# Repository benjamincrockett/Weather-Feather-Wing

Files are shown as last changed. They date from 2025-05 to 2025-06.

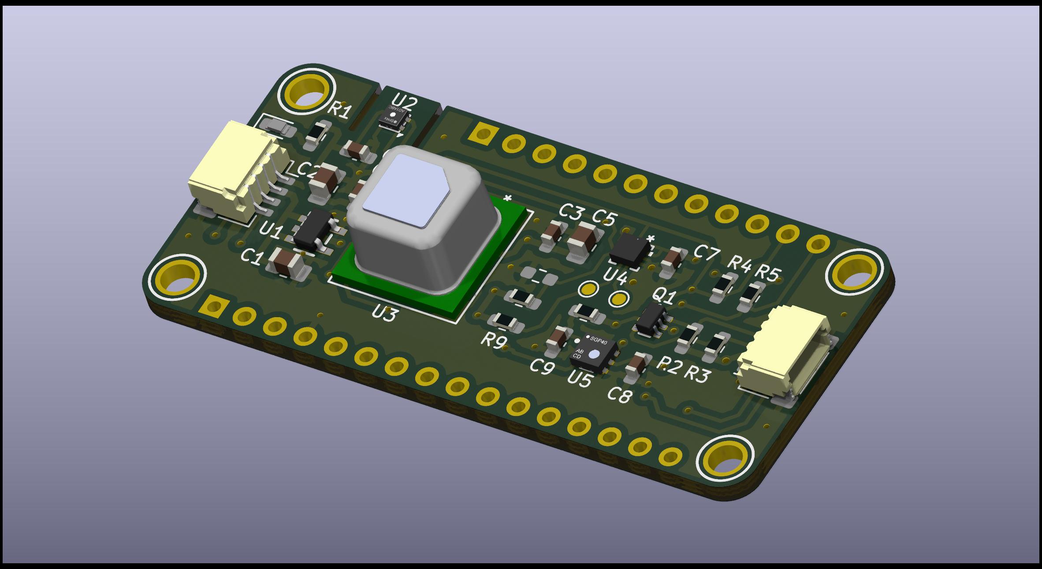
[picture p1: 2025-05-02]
Renders/Weather-Feather-Wing CCA 3D.jpg

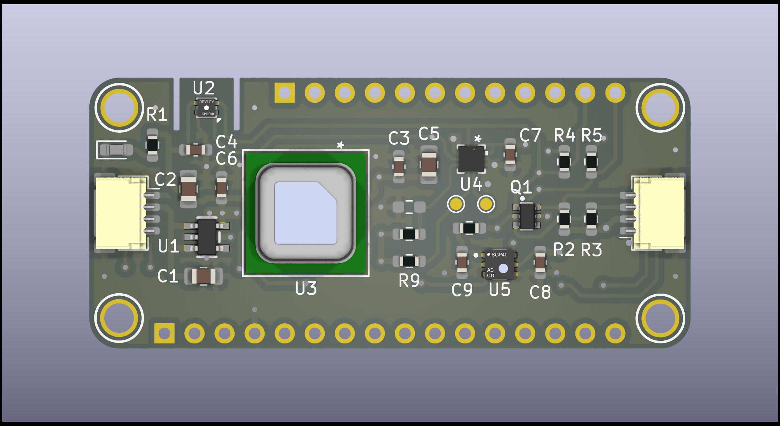
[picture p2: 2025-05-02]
Renders/Weather-Feather-Wing CCA.jpg

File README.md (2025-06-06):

# Weather-Feather-Wing
 An online interactive viewer is available at https://kicanvas.org/. Copy and paste the URL of this repository into the text box on the KiCanvas website to get started. 

# Software
A software example for this project is available in the following repository: https://github.com/benjamincrockett/Air-Quality-Weather

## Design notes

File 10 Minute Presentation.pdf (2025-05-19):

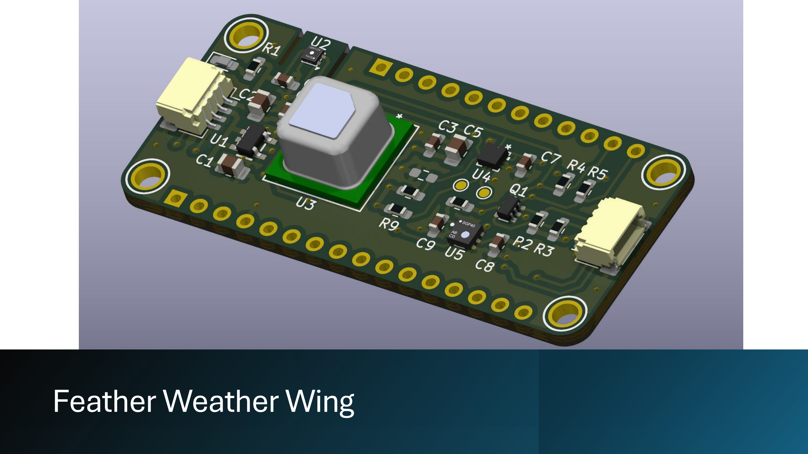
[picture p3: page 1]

# Feather Weather Wing

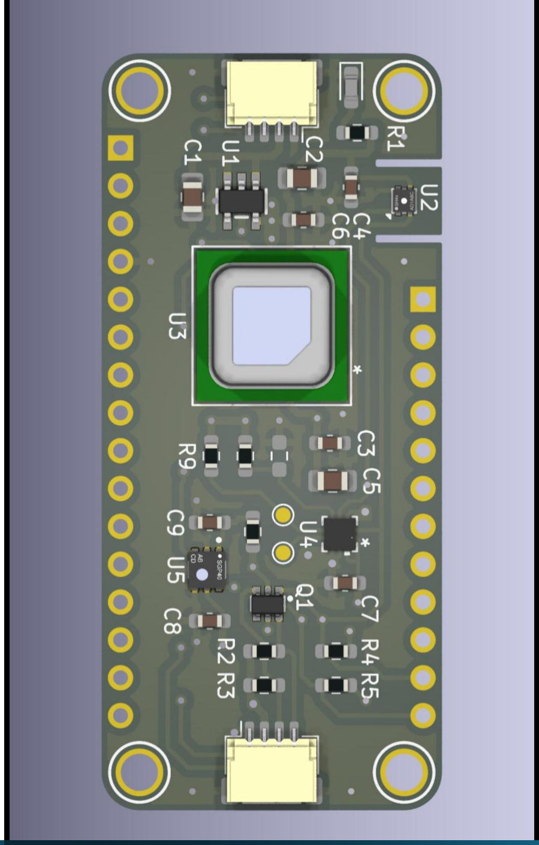
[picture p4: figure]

# Feather Weather Wing: What is it?

# - It is a 0.9-inch x 2.0-inch circuit board that combines four

environmental sensors in the Feather Wing form factor.

# - Sensirion SHT45 – Humidity & Temperature - Sensirion SCD41 – CO2, Temperature, & Humidity

- Benefits from an atmospheric air pressure input.

# - Sensirion SGP40 – Indoor Air Quality

- Benefits from a humidity input.

# - Bosch BMP390 – Atmospheric Air Pressure - 4 Layer PCB - Designed using KiCad 9.0 - PCB fabricated by OSHPARK

# Feather Specification

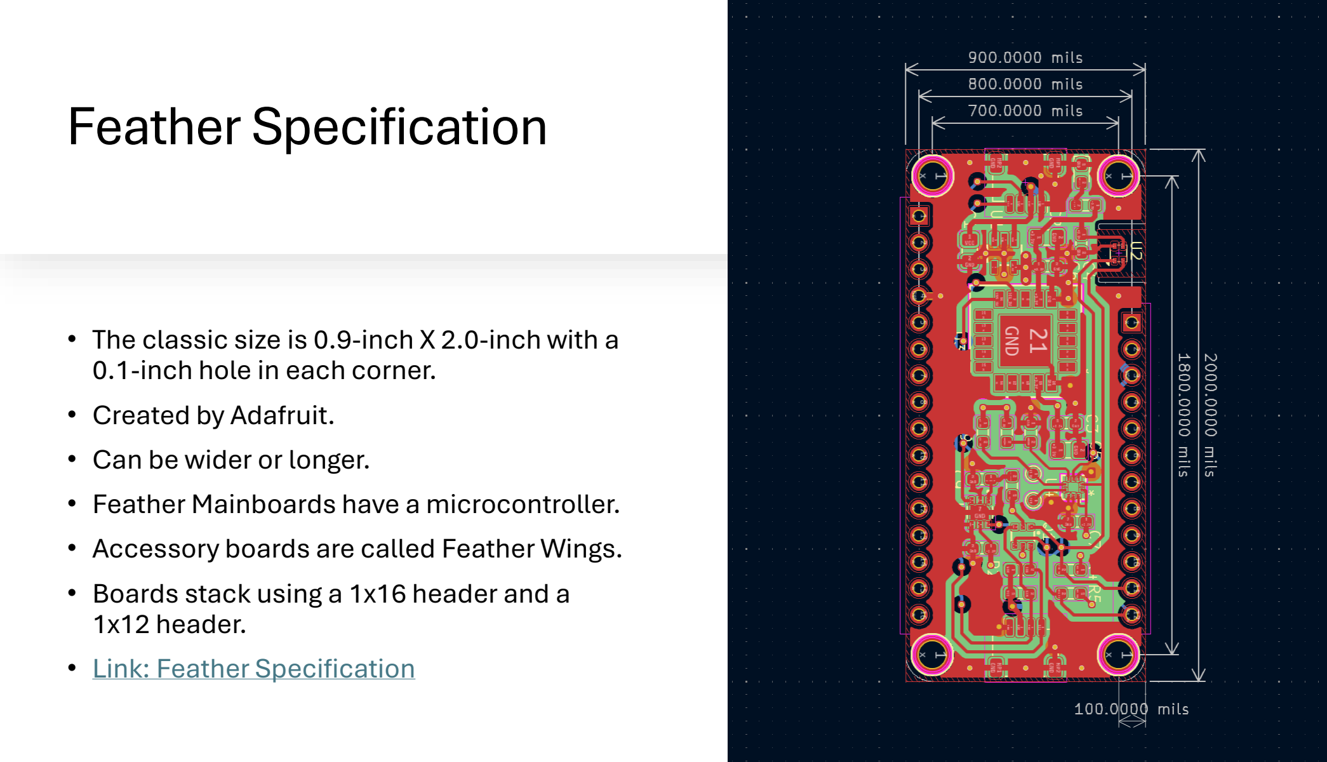
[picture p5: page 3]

# - The classic size is 0.9-inch X 2.0-inch with a

0.1-inch hole in each corner.
- Created by Adafruit.
- Can be wider or longer.
- Feather Mainboards have a microcontroller.
- Accessory boards are called Feather Wings.

# - Boards stack using a 1x16 header and a

1x12 header.
- Link: Feather Specification (https://learn.adafruit.com/adafruit-feather/feather-specification)

# STEMMA QT

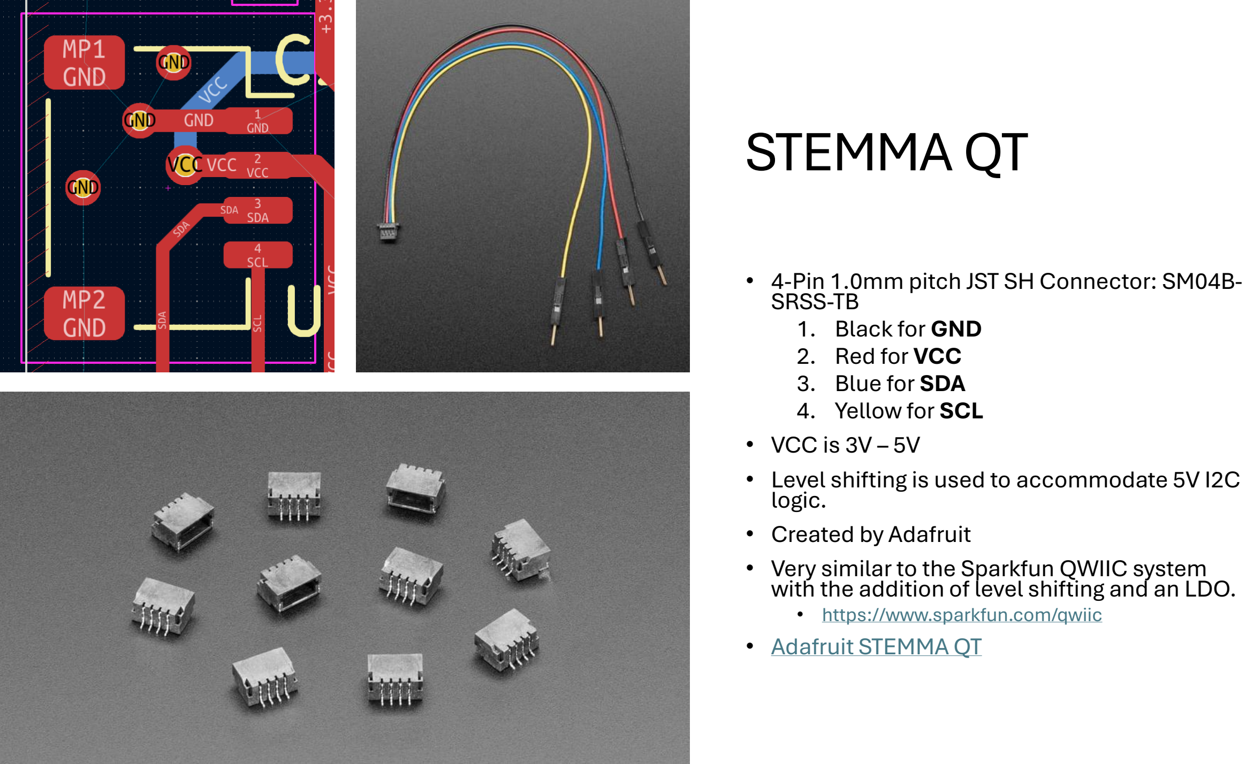
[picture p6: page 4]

# - 4-Pin 1.0mm pitch JST SH Connector: SM04B-SRSS-TB 1. Black for GND 2. Red for VCC 3. Blue for SDA 4. Yellow for SCL - VCC is 3V – 5V - Level shifting is used to accommodate 5V I2C

logic.

# - Created by Adafruit - Very similar to the Sparkfun QWIIC system

with the addition of level shifting and an LDO.

## - https://www.sparkfun.com/qwiic

- Adafruit STEMMA QT (https://learn.adafruit.com/introducing-adafruit-stemma-qt/technical-specs)

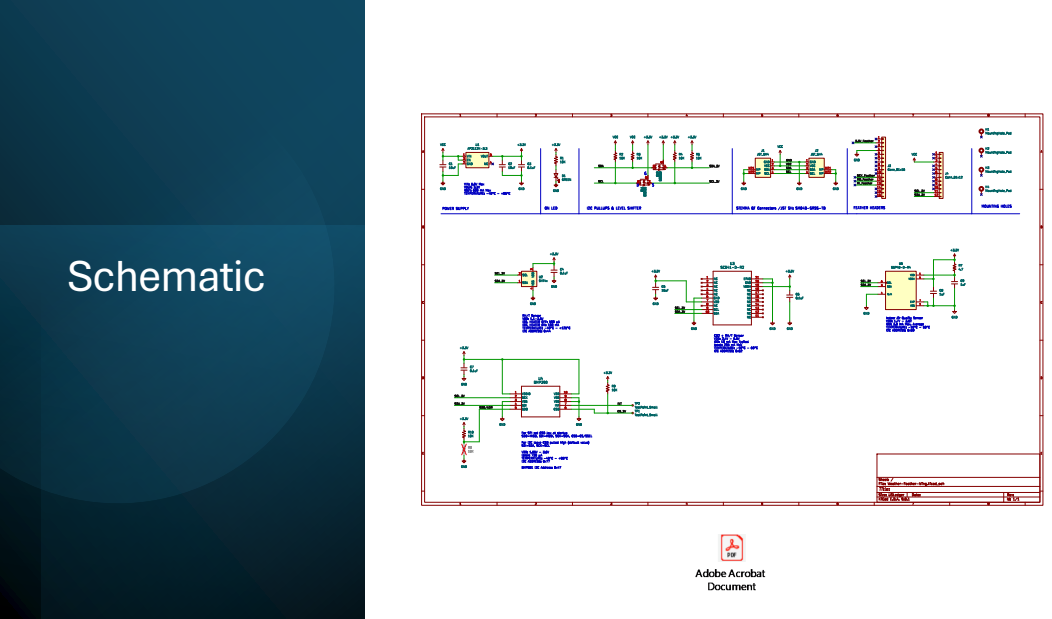
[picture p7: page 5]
Schematic

# Bill Of Materials (BOM)

## Index Reference Description

## Manufacturer Part Number

## Manufacturer

Name | Quantity DNP
1 C1,C2,C5 | CAP CER 10UF 10V X7R 0805 C0805C106K8RACTU | KEMET | 3
2 | C3,C4,C6,C7 | CAP CER 0.1UF 10V X7R 0603 | C0603C104K8RACTU | KEMET | 4
3 C8,C9 | CAP CER 1UF 16V X7R 0603 | C0603C105K4RACTU | KEMET | 2
4 | D1 | LED GREEN DIFFUSED 0603
| | SMD | KT EELP41.12-S2U1-25-2X4X-
| | | 5-R18 | ams-OSRAM USA INC. | 1

5 J1,J2

| | CONN HEADER SMD R/A
| | 4POS 1MM | SM04B-SRSS-TB | JST Sales America Inc. | 2
6 | J3 | Conn_01x16 | - | - | 0 | DNP
7 J4 | Conn_01x12 | - | - | 0 DNP
8 | Q1 | MOSFET 2N-CH 50V 0.2A
| | SOT363 | BSS138DWQ-7 | Diodes Incorporated | 1

9 R1,R2,R3,R4,R5,R9,R10

| | RES SMD 10K OHM 1% 1/10W
| | 0603 | CRCW060310K0FKEA | Vishay Dale | 7
10 | R7 | RES SMD 4.7 OHM 1% 1/10W
| | 0603 | CRCW06034R70FNEA | Vishay Dale | 1

11 R8

| | RES SMD 10K OHM 1% 1/10W
0603 | - | - | 0 DNP
12 | U1 | IC REG LINEAR 3.3V 600MA
| | SOT-25 | AP2112K-3.3TRG1 | Diodes Incorporated | 1
13 U2 | DIGITAL RH/TEMP W/FILTER | SHT45-AD1F-R2 | Sensirion AG | 1
14 | U3 | SENSOR AIR QUALITY I2C
| | OUTPUT | SCD41-D-R2 | Sensirion AG | 1
15 U4 | SENSOR 18.13PSIA 10LGA | BMP390 | Bosch Sensortec | 1
16 | U5 | SENSOR AIR QUALITY I2C
| | OUTPUT | SGP40-D-R4 | Sensirion AG | 1

# Top: Signal /PWR /GND

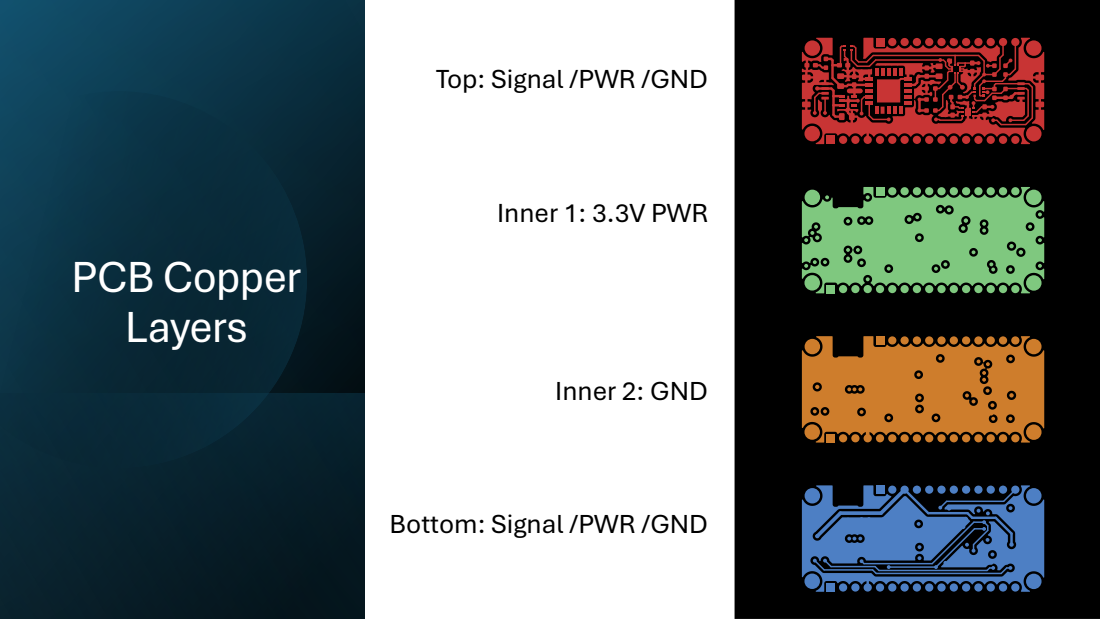
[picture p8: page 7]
PCB Copper Layers; Inner 1: 3.3V PWR; Inner 2: GND

Bottom: Signal /PWR /GND

# Stackup: Four Layer OSHPARK

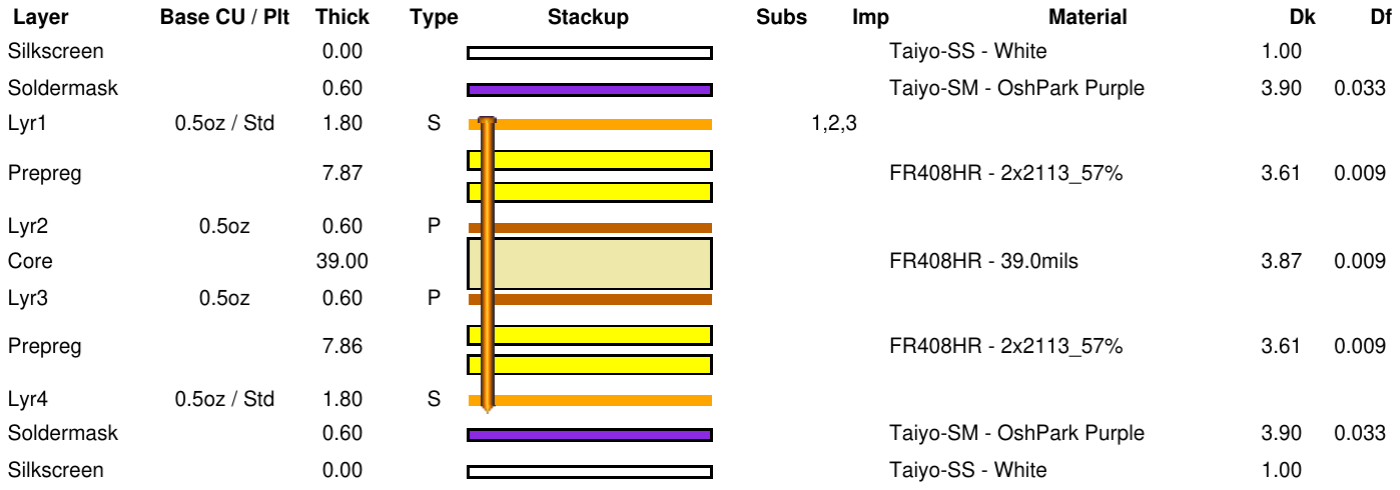
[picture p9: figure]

# Data Logging and Visualization

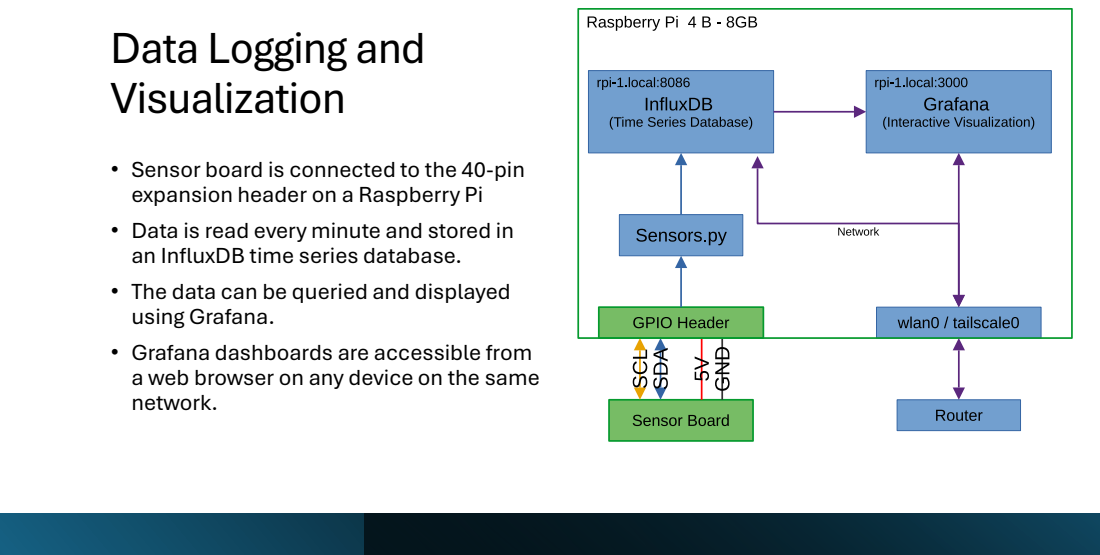
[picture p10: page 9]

• Sensor board is connected to the 40-pin
expansion header on a Raspberry Pi
• Data is read every minute and stored in
an InfluxDB time series database.
• The data can be queried and displayed
using Grafana.
• Grafana dashboards are accessible from
a web browser on any device on the same
network.

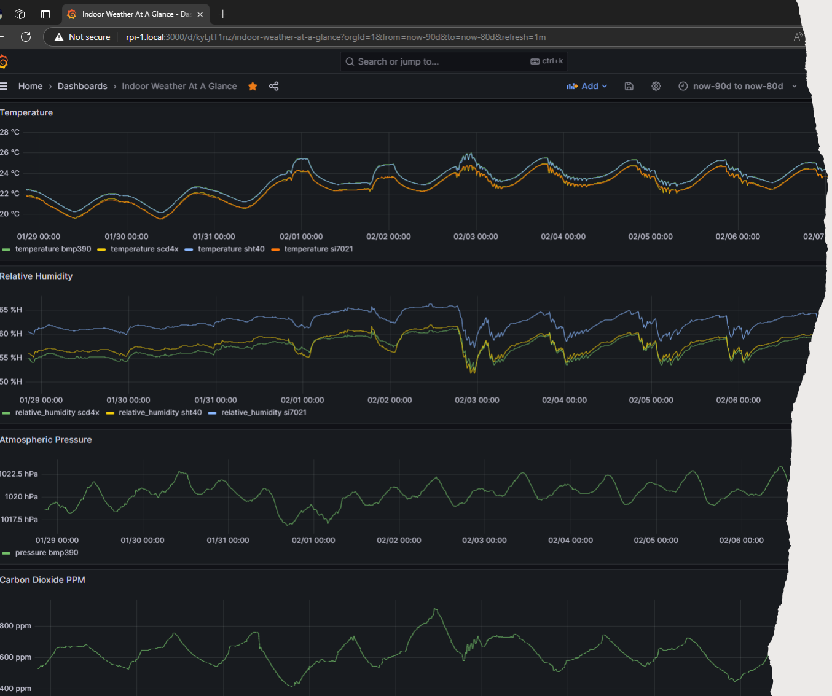
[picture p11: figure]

# Grafana Dashboard

# Data visualization

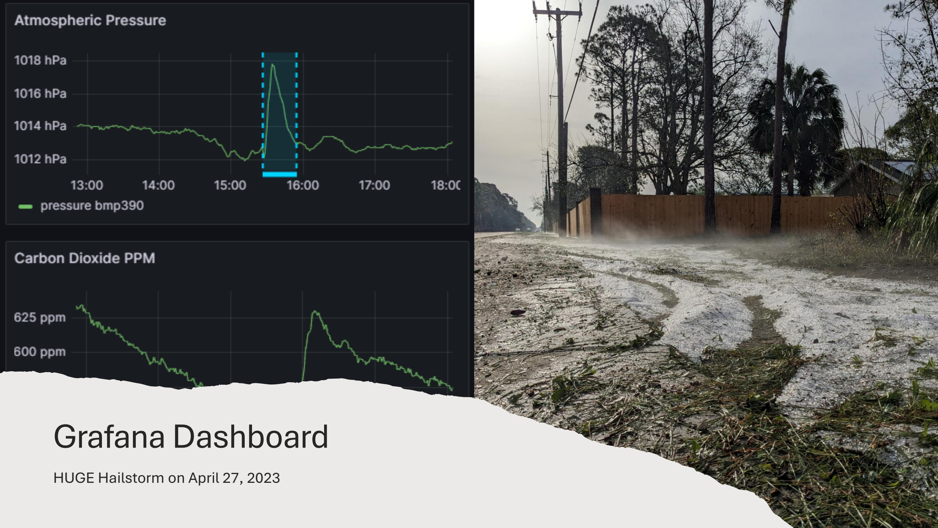
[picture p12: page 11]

# Grafana Dashboard

# HUGE Hailstorm on April 27, 2023

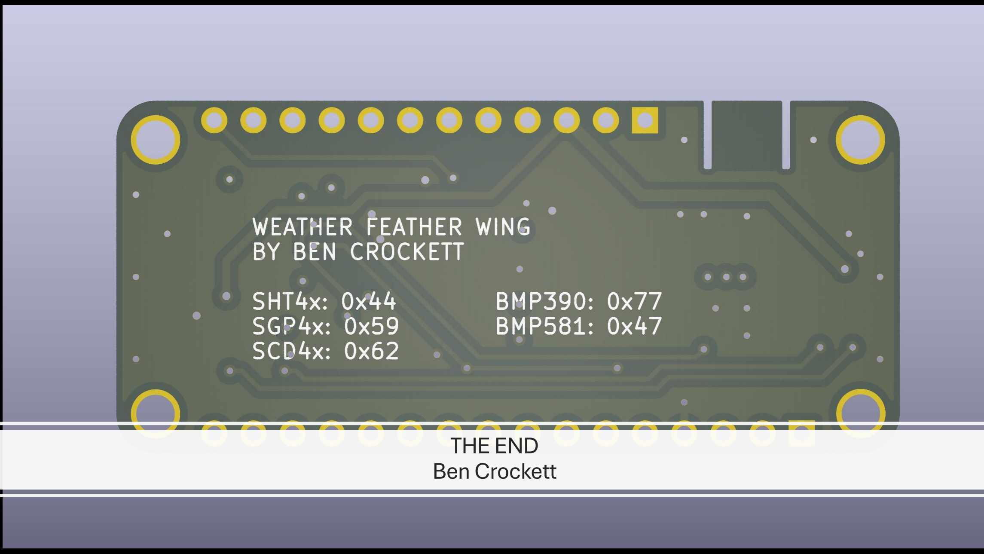
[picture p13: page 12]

# THE END Ben Crockett

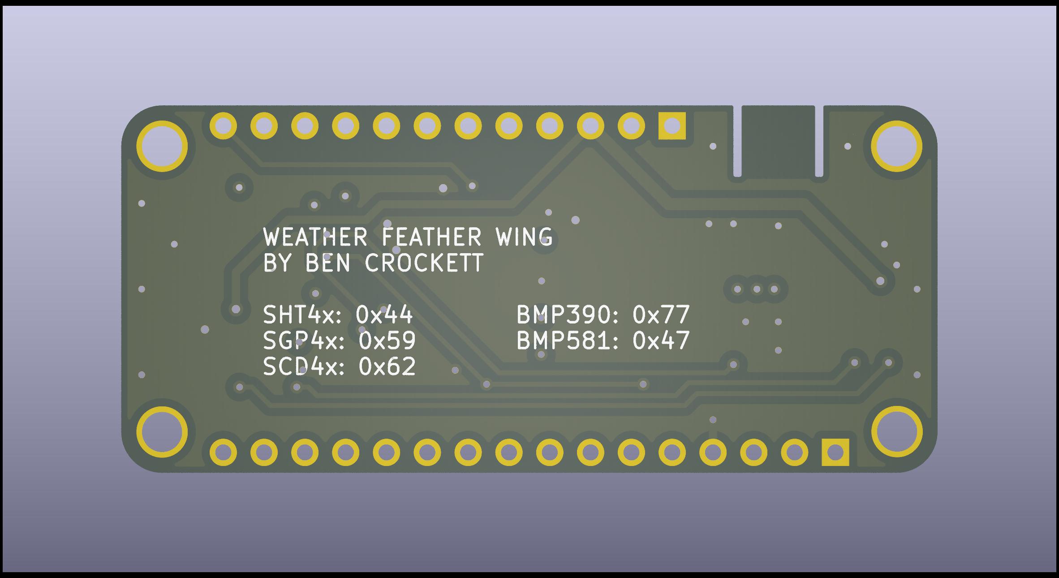
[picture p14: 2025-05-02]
Renders/Weather-Feather-Wing PCB Back.jpg

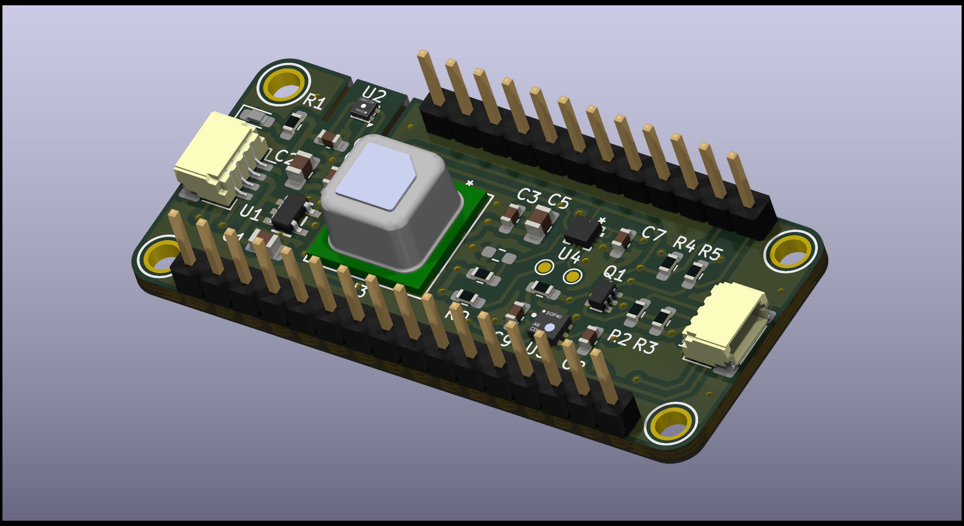
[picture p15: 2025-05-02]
Renders/Weather-Feather-Wing CCA 3D Headers.jpg

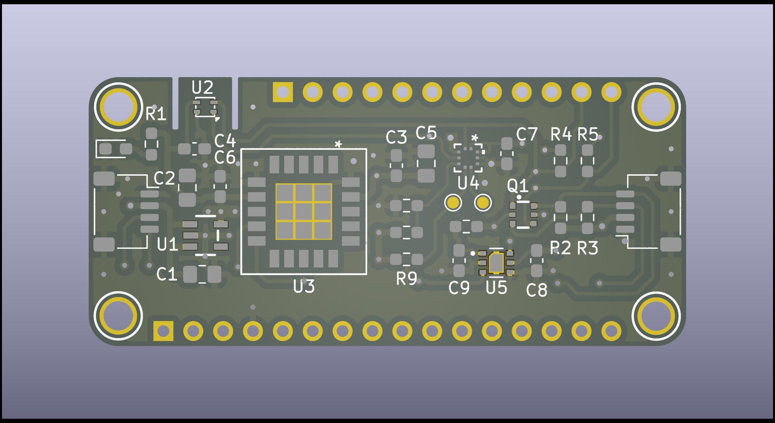
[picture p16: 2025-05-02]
Renders/Weather-Feather-Wing PCB with Paste.jpg

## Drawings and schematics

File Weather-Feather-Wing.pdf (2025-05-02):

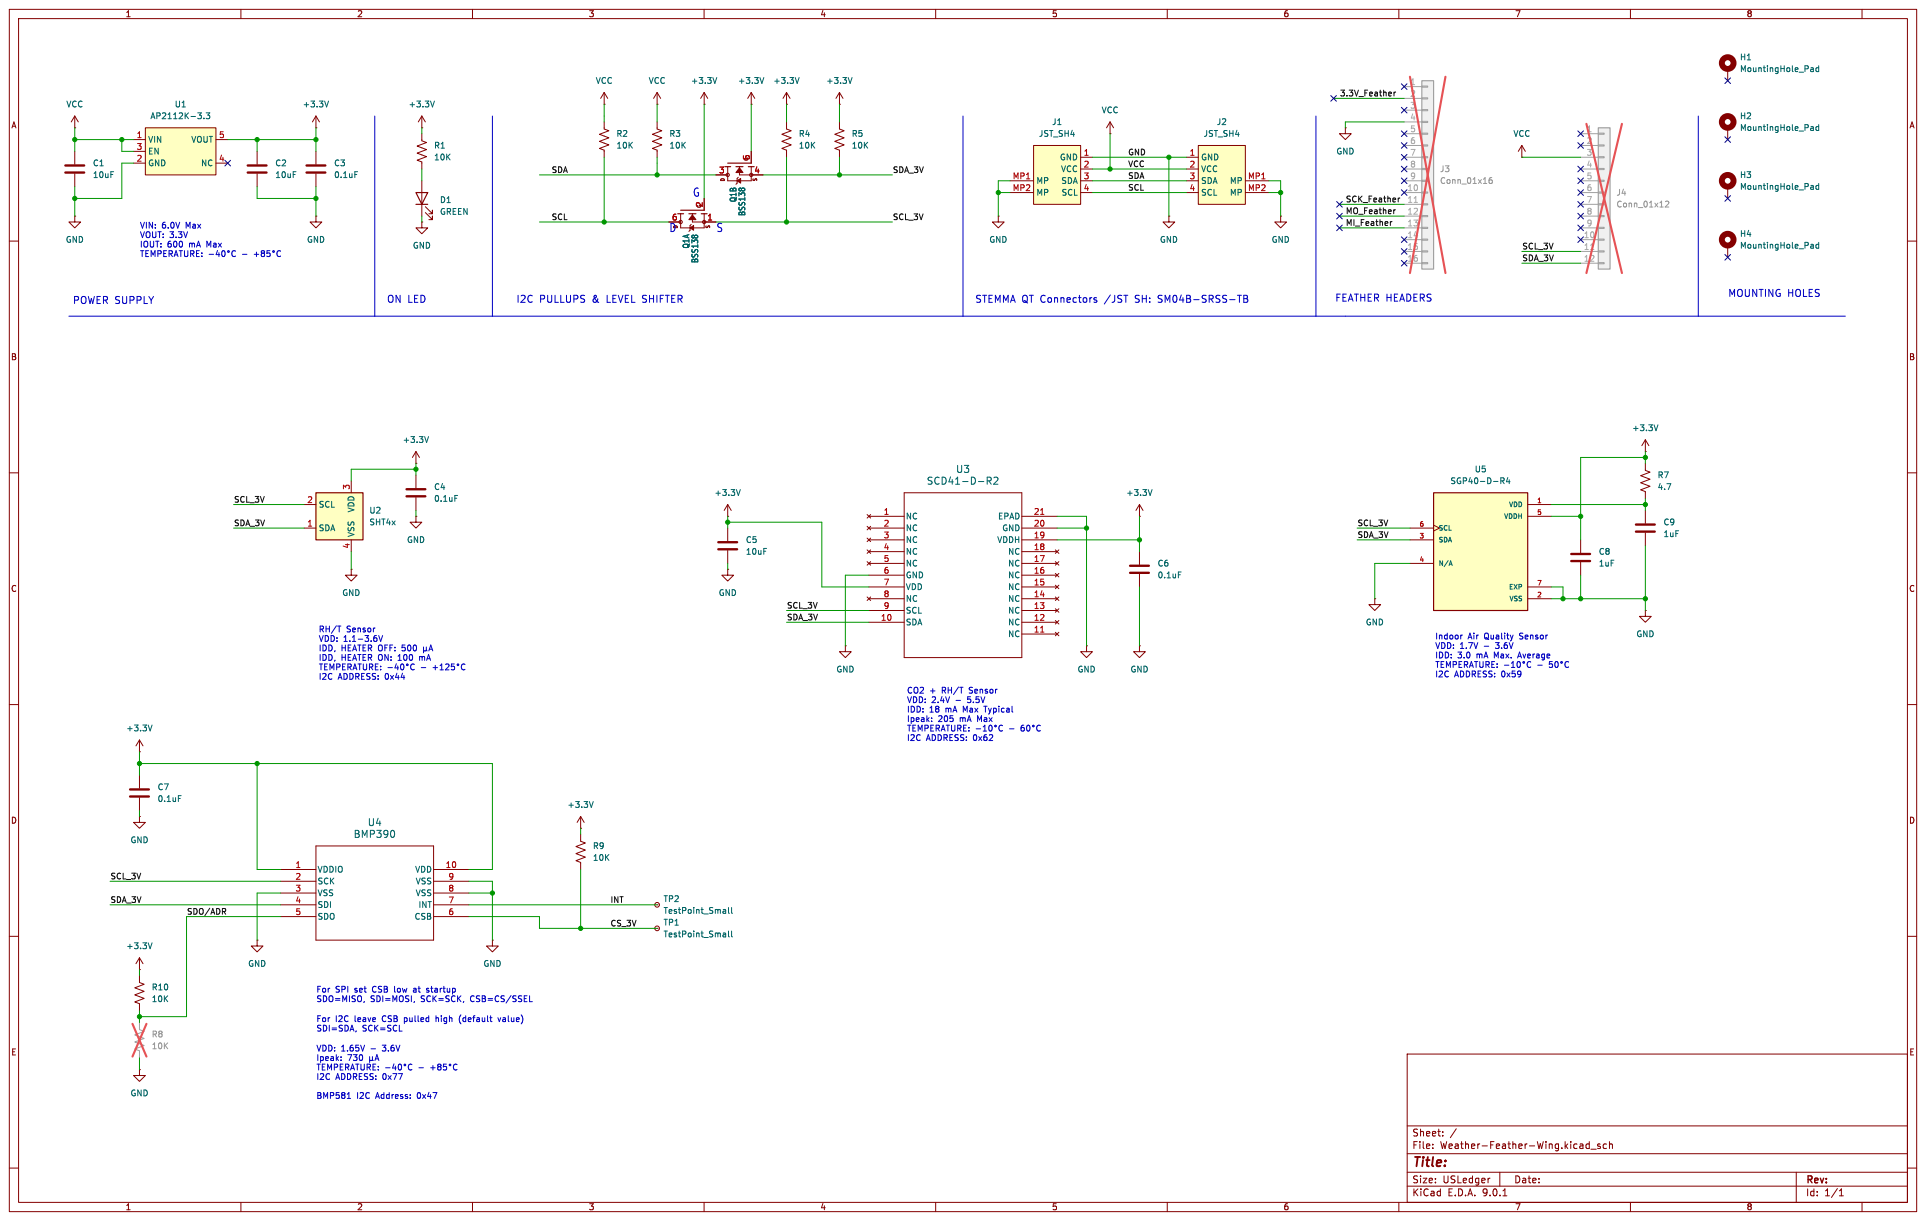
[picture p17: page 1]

JST_SH4 VCC GND 1 VCC 2 SDA 3 SCL 4 MP MP1 MP MP2

IOUT: 600 mA Max TEMPERATURE: þÿ-40°C- þÿ+85°C

Indoor Air Quality Sensor VDD: 1.7V - 3.6V

IDD, HEATER OFF: 500 þÿµA
IDD, HEATER ON: 100 mA
TEMPERATURE: þÿ-40°C- þÿ+125°C

IDD: 3.0 mA Max. Average TEMPERATURE: þÿ-10°C- þÿ50°C

IDD: 18 mA Max Typical
Ipeak: 205 mA Max TEMPERATURE: þÿ-10°C- þÿ60°C

Id: 1/1 Title: File: Weather-Feather-Wing.kicad_sch Sheet: /

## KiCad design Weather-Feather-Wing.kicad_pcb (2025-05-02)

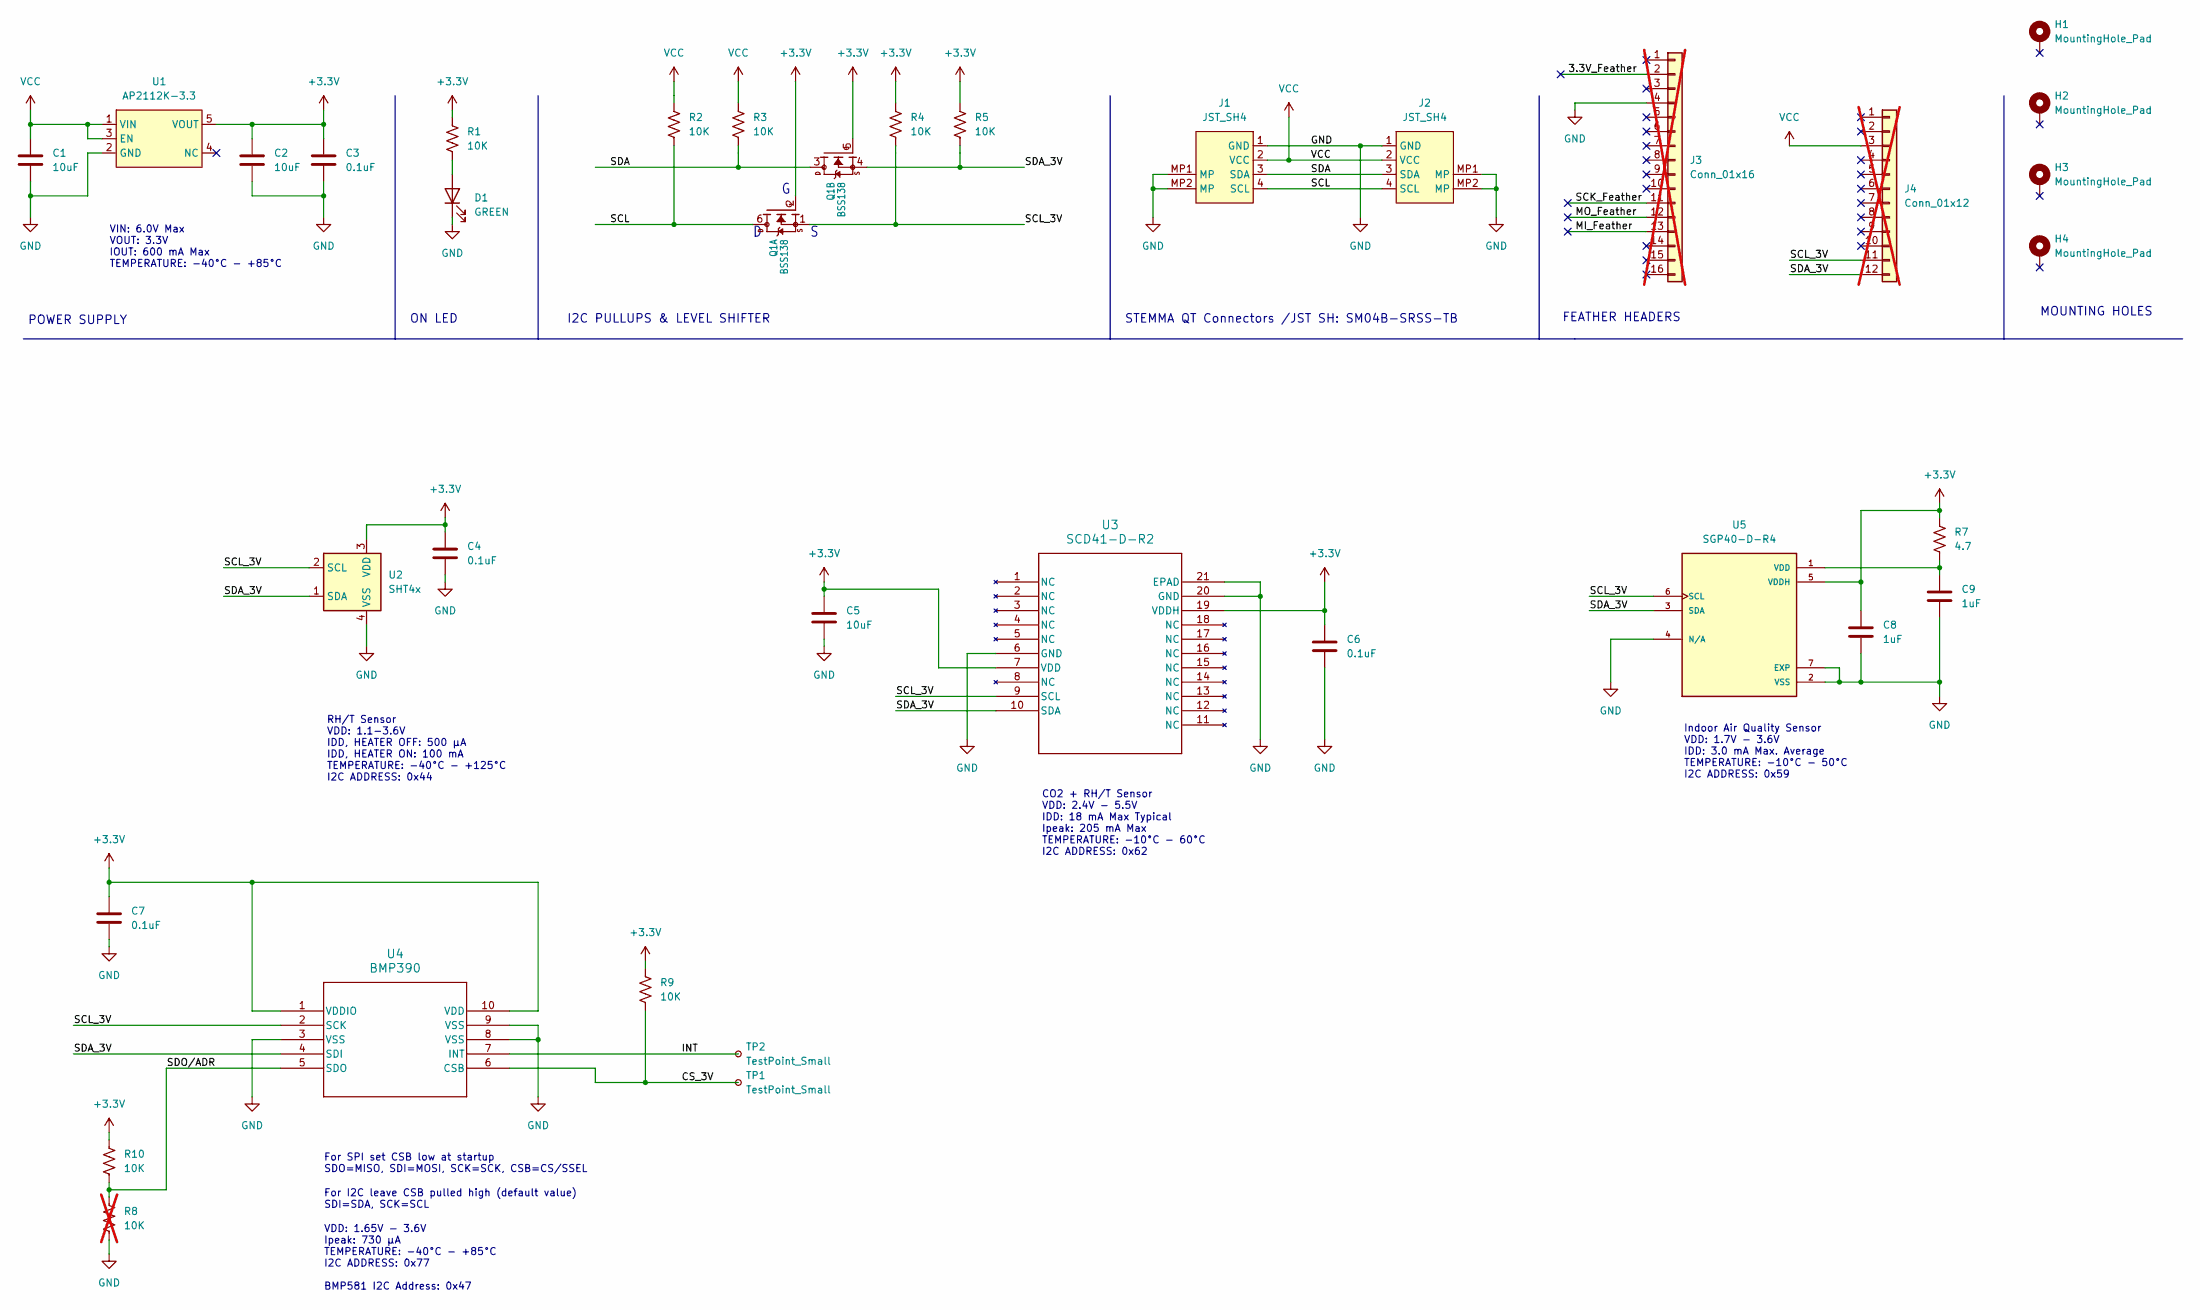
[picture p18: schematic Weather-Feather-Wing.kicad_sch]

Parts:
C1, C2, C5: 10uF; C_0805_2012Metric_Pad1.18x1.45mm_HandSolder
C3, C4, C6, C7: 0.1uF; C_0603_1608Metric_Pad1.08x0.95mm_HandSolder
C8, C9: 1uF; C_0603_1608Metric_Pad1.08x0.95mm_HandSolder
D1: GREEN; LED_0603_1608Metric_Pad1.05x0.95mm_HandSolder
H1, H2, H3, H4: MountingHole_Pad; MOUNTINGHOLE_2.5_PLATED
J1, J2: JST_SH4; JST_SH_SM04B-SRSS-TB_1x04-1MP_P1.00mm_Horizontal
J3: Conn_01x16; PinHeader_1x16_P2.54mm_Vertical; not fitted
J4: Conn_01x12; PinHeader_1x12_P2.54mm_Vertical; not fitted
Q1: BSS138; SOT363
R1, R2, R3, R4, R5, R9, R10: 10K; R_0603_1608Metric_Pad0.98x0.95mm_HandSolder
R7: 4.7; R_0603_1608Metric_Pad0.98x0.95mm_HandSolder
R8: 10K; R_0603_1608Metric_Pad0.98x0.95mm_HandSolder; not fitted
TP1, TP2: TestPoint_Small; TestPoint_Pad_D1.0mm
U1: AP2112K-3.3; SOT23-5
U2: SHT4x; SHT4X
U3: SCD41-D-R2; QFN20_SCD41-D-R2_SEN
U4: BMP390; 10LGA_2X2X0p75_BOS
U5: SGP40-D-R4; XCDR_SGP40-D-R4; PARTREV 1.2

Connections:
+3.3V: C2.1, C3.1, C4.1, C5.1, C6.1, C7.1, C8.1, Q1.2 (G), Q1.5 (G), R1.1, R4.1, R5.1, R7.1, R9.1, R10.1, U1.5 (VOUT), U2.3 (VDD), U3.7 (VDD), U3.19 (VDDH), U4.1 (VDDIO), U4.10 (VDD), U5.5 (VDDH)
/3.3V_Feather: J3.2
/CS_3V: R9.2, TP1.1, U4.6 (CSB)
/INT: TP2.1, U4.7 (INT)
/MI_Feather: J3.13
/MO_Feather: J3.12
/SCK_Feather: J3.11
/SCL: J1.4 (SCL), J2.4 (SCL), Q1.6 (D), R2.2
/SCL_3V: J4.11, Q1.1 (S), R4.2, U2.2 (SCL), U3.9 (SCL), U4.2 (SCK), U5.6 (SCL)
/SDA: J1.3 (SDA), J2.3 (SDA), Q1.3 (D), R3.2
/SDA_3V: J4.12, Q1.4 (S), R5.2, U2.1 (SDA), U3.10 (SDA), U4.4 (SDI), U5.3 (SDA)
/SDO/ADR: R8.2, R10.2, U4.5 (SDO)
GND: C1.2, C2.2, C3.2, C4.2, C5.2, C6.2, C7.2, C8.2, C9.2, D1.1 (K), J1.1 (GND), J1.MP1 (MP), J1.MP2 (MP), J2.1 (GND), J2.MP1 (MP), J2.MP2 (MP), J3.4, R8.1, U1.2 (GND), U2.4 (VSS), U3.6 (GND), U3.20 (GND), U3.21 (EPAD), U4.3 (VSS), U4.8 (VSS), U4.9 (VSS), U5.2 (VSS), U5.4 (N/A), U5.7 (EXP)
unnamed: D1.2 (A), R1.2
unnamed: C9.1, R7.2, U5.1 (VDD)
VCC: C1.1, J1.2 (VCC), J2.2 (VCC), J4.3, R2.1, R3.1, U1.1 (VIN), U1.3 (EN)

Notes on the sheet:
ON LED
POWER SUPPLY
I2C PULLUPS & LEVEL SHIFTER
RH/T Sensor VDD: 1.1-3.6V IDD, HEATER OFF: 500 µA IDD, HEATER ON: 100 mA TEMPERATURE: -40°C - +125°C I2C ADDRESS: 0x44
FEATHER HEADERS
MOUNTING HOLES
VIN: 6.0V Max VOUT: 3.3V IOUT: 600 mA Max TEMPERATURE: -40°C - +85°C
VDD: 1.65V - 3.6V Ipeak: 730 µA TEMPERATURE: -40°C - +85°C I2C ADDRESS: 0x77 BMP581 I2C Address: 0x47
STEMMA QT Connectors /JST SH: SM04B-SRSS-TB
Indoor Air Quality Sensor VDD: 1.7V - 3.6V IDD: 3.0 mA Max. Average TEMPERATURE: -10°C - 50°C I2C ADDRESS: 0x59
CO2 + RH/T Sensor VDD: 2.4V - 5.5V IDD: 18 mA Max Typical Ipeak: 205 mA Max TEMPERATURE: -10°C - 60°C I2C ADDRESS: 0x62
For I2C leave CSB pulled high (default value) SDI=SDA, SCK=SCL
For SPI set CSB low at startup SDO=MISO, SDI=MOSI, SCK=SCK, CSB=CS/SSEL

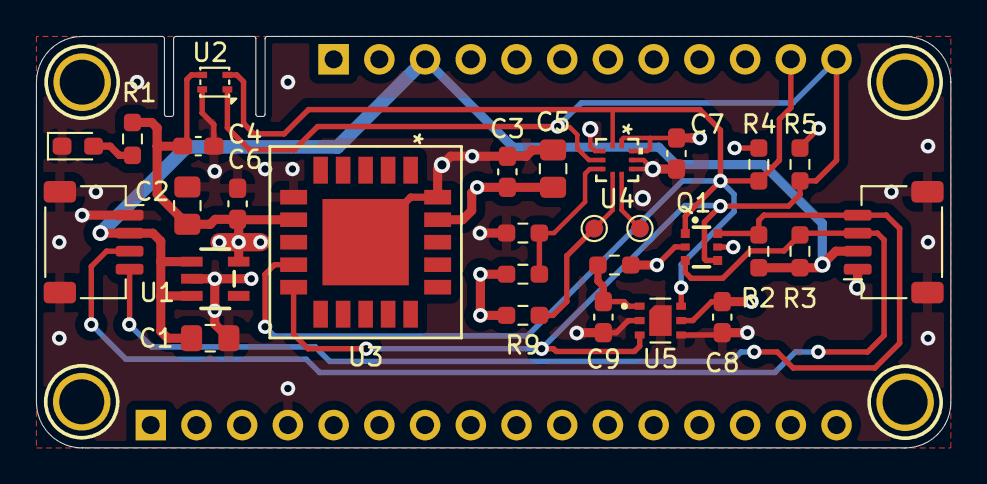
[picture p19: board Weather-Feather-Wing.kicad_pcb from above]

Board: 4 copper layers, 50.8 x 22.9 mm, 35 parts (0 on the bottom side), 12 nets.

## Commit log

2025-03-22 Initial Release
    [Weather-Feather-Wing.kicad_pcb, Weather-Feather-Wing.kicad_sch]
2025-03-25 Corrections and improvements.
    [Weather-Feather-Wing.kicad_pcb, Weather-Feather-Wing.kicad_sch]
2025-03-26 As ordered from OSH Park.
    [Weather-Feather-Wing.kicad_pcb, Weather-Feather-Wing.kicad_sch]
2025-04-07 Cleanup and updates
    [Weather-Feather-Wing.kicad_pcb, Weather-Feather-Wing.kicad_sch]
2025-04-23 Updates after building the board.
    [Weather-Feather-Wing.kicad_pcb, Weather-Feather-Wing.kicad_sch]
2025-05-02 Design corrections, moved both header pins 50 mils closer to their respective edges.
    [Weather-Feather-Wing.kicad_pcb, Weather-Feather-Wing.kicad_sch]
2025-06-06 Added the PowerPoint file for the presentation.
